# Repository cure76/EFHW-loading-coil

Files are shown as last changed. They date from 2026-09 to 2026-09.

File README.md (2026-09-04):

# Удлиняющая катушка EFHW 100 мкГн

Параметрические модели OpenSCAD: каркас однослойной катушки и седло клеммы полотна под М4.

## Файлы

| Файл | Что печатать |
| --- | --- |
| `EFHW_Loading_Coil_100_mkgn_1mm.scad` | Каркас (1 шт.) |
| `EFHW_terminal_saddle_M4.scad` | Седло клеммы (2 шт.) |

Превью обмотки и термоусадки в каркасе (`show_winding`, `show_shrink`) только в F5, в STL не попадают.

После F5/F6 смотри консоль OpenSCAD (`echo`): витки, длины, Ø буртика, Ø термоусадки.

## Каркас (дефолты)

- Индуктивность по Уилеру 1928, однослойно, виток к витку
- Диаметр намотки (наружный Ø трубы) **55 мм**
- Провод **ПЭТВ-2 1 мм** (медь 1.0 мм, с эмалью ≈ 1.093 мм)
- Стенка 2 мм, канал сквозной (охлаждение)
- Внутри, со стороны отверстий: плоская полка **1 мм** на всю длину, по хорде до стенок канала (шайбы под М4, силовой элемент). Отверстия М4 и отводы сквозные через полку, сверлить не нужно.
- Буртики на 0.5 мм выше провода
- Отверстия: отвод обмотки **1.5 мм** вплотную к буртикам (зазор 0.3 мм), болты **М4** 4.4 мм, с одной стороны (−Y)
- `spare_turns = 8` — в окне намотки место под 8 лишних витков (до 59 вплотную)

Если сменил провод или Ø, подставь в седло `flange_od` и `shrink_wall` из echo каркаса.

## Намотка и индуктивность

Мотать **виток к витку** ПЭТВ-2 1 мм между буртиками. Начинать и кончать через отверстия 1.5 мм.

| Витки | L (Уилер), мкГн | Провод (витки) | С отводами 10 см × 2 |
| --- | --- | --- | --- |
| 51 | ≈ 99.5 | ≈ 8.99 м | ≈ 9.19 м |
| 52 | ≈ 102 | ≈ 9.16 м | ≈ 9.36 м |
| 58 | ≈ 118 | ≈ 10.22 м | ≈ 10.42 м |
| 59 | ≈ 120 | ≈ 10.40 м | ≈ 10.60 м |

Среднее Ø витка ≈ 56.1 мм (труба 55 + эмаль), ≈ 17.6 см на виток. Окно каркаса вмещает **59** витков вплотную.

Резать с запасом под окно: **10.6–11 м** ПЭТВ-2 1 мм. После намотки с каждой стороны должно остаться по ~10 см на отвод.

Практический ориентир Уилера: **примерно 100–102 мкГн** на 51–52 витках. Один виток ≈ **+2.6 мкГн**. Если прибор показывает меньше — домотай (место есть до 59).

1. Намотай **52** витка виток к витку.
2. Измерь L-метром (лучше на каркасе, как будет в антенне).
3. Если меньше 100 — добавляй витки до 100–102 (окно до 59).
4. Если больше 100–102 — сними лишнее.
5. Не растягивай витки: шаг заложен виток к витку.

Цифры — расчёт Уилера для воздушного каркаса. Печать и лак чуть сдвинут L; ориентир — прибор, не echo.

## Сборка

1. Намотка, отводы через 1.5 мм на болты М4 (гайка внутри канала).
2. Лак, сушка.
3. Термоусадка **на всю катушку**, включая буртики; стержни М4 снаружи. Мин. внутр. Ø трубки до усадки — в echo (дефолт ≥ ~60 мм).
4. Два седла **поверх усадки** (не на голый пластик). Одна жила **П-274М** (Ø ≤ 2.3 мм) в щель 3 мм под шляпку, петля на болт. Снутри на плоскую полку — шайба М4 и гайка.

Седло по умолчанию под Ø буртика 58.186 мм и стенку усадки 0.6 мм.

## Мощность (оценка, не паспорт)

Каркас PETG + усадка на всё. Узкое место — нагрев, не медь.

| Режим | Ориентир |
| --- | --- |
| SSB | до 100 Вт PEP |
| CW | 50–70 Вт |
| FT8 | 20–40 Вт |

После FT8 каркас должен быть тёплым, не обжигающим.

## Печать

Предпочтительно **PETG** (улица, УФ). PLA для постоянной установки хуже.

Тесты расчёта Уилера:

```bash
cd tests && python3 -m unittest test_coil_math -v
```

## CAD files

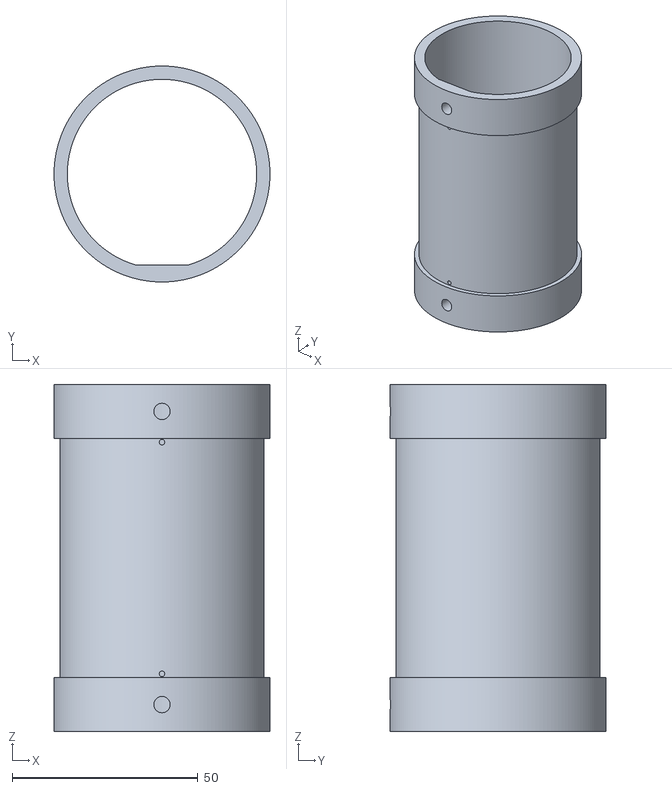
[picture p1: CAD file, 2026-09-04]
EFHW_Loading_Coil_100_mkgn_1mm.stl
58.2 x 58.2 x 93.5

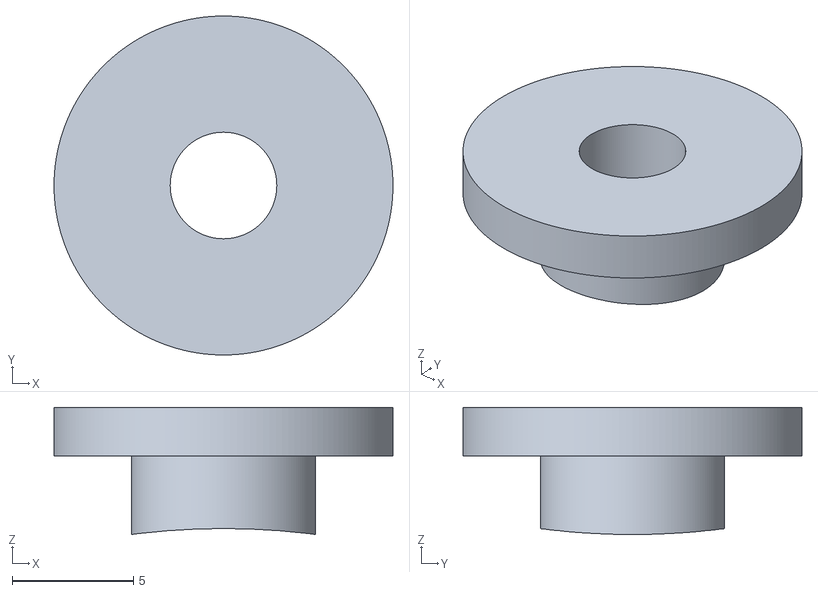
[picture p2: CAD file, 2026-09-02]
EFHW_terminal_saddle_M4.stl
14.0 x 14.0 x 5.25

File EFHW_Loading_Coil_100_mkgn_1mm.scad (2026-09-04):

$fn = $preview ? 64 : 160;

/* [Coil] */
L_uH = 100;
winding_d = 55;
wire_cu_d = 1.0;
wire_od = 0; // 0 = авто ПЭТВ-2

/* [Former] */
wall = 2;
flange_len = 14.5;
flange_over_wire = 0.5;
m4_d = 4.4;
lead_d = 1.5; // отверстие под отвод ПЭТВ-2
lead_flange_gap = 0.3; // зазор от края отверстия до буртика, мм
spare_turns = 8; // запас окна намотки (витков)
rib_t = 1; // полка внутрь канала, мм (хорда до стенок цилиндра)

/* [Preview] */
show_winding = false;
show_shrink = false;
shrink_wall = 0.6;

function in_from_mm(mm) = mm / 25.4;

function petv2_od(cu_d) = cu_d + 0.093;

function wire_od_eff(cu_d, od) = od <= 0 ? petv2_od(cu_d) : od;

function wheeler_n(L, r_mm, pitch_mm) =
    let (
        r = in_from_mm(r_mm),
        p = in_from_mm(pitch_mm),
        disc = pow(10 * L * p, 2) + 36 * L * pow(r, 3)
    )
    (10 * L * p + sqrt(disc)) / (2 * r * r);

function wheeler_L(N, r_mm, pitch_mm) =
    let (
        r = in_from_mm(r_mm),
        ell = in_from_mm(N * pitch_mm)
    )
    r * r * N * N / (9 * r + 10 * ell);

od = wire_od_eff(wire_cu_d, wire_od);
inner_d = winding_d - 2 * wall;
pitch = od;
r_mm = (winding_d + od) / 2;
N_exact = wheeler_n(L_uH, r_mm, pitch);
N_finite = N_exact == N_exact && N_exact > 0 && N_exact < 1e6;
N = N_finite ? max(1, round(N_exact)) : 0;
winding_len = (N + spare_turns) * pitch;
length = winding_len + 2 * flange_len;
flange_od = winding_d + 2 * (od + flange_over_wire);
L_actual = N_finite ? wheeler_L(N, r_mm, pitch) : 0;
use_mid_leads = (winding_len - 2 * lead_d - 2 * lead_flange_gap) < lead_d;
rib_w = (rib_t > 0 && rib_t < inner_d / 2)
    ? 2 * sqrt(pow(inner_d / 2, 2) - pow(inner_d / 2 - rib_t, 2))
    : 0;
rib_ok = rib_t > 0 && rib_t < inner_d / 2 && rib_w > m4_d;
geometry_ok = inner_d > 0 && N_finite && winding_len > 0 && spare_turns >= 0 && rib_ok;

function lead_z(sign) =
    use_mid_leads
        ? sign * winding_len / 4
        : sign * (winding_len / 2 - lead_d / 2 - lead_flange_gap);

module radial_cut(d, z) {
    translate([0, 0, z])
        rotate([90, 0, 0])
            cylinder(h = flange_od / 2 + 5, d = d, center = false);
}

module inner_rib() {
    intersection() {
        cylinder(h = length, d = inner_d, center = true);
        translate([0, -inner_d / 2 + rib_t / 2, 0])
            cube([inner_d + 1, rib_t, length], center = true);
    }
}

module former() {
    difference() {
        union() {
            difference() {
                cylinder(h = length, d = winding_d, center = true);
                cylinder(h = length + 2, d = inner_d, center = true);
            }
            for (z = [-(length / 2 - flange_len / 2), length / 2 - flange_len / 2])
                translate([0, 0, z])
                    difference() {
                        cylinder(h = flange_len, d = flange_od, center = true);
                        cylinder(h = flange_len + 1, d = winding_d, center = true);
                    }
            inner_rib();
        }
        for (sign = [-1, 1]) {
            radial_cut(m4_d, sign * (length / 2 - flange_len / 2));
            radial_cut(lead_d, lead_z(sign));
        }
    }
}

module preview_winding() {
    difference() {
        cylinder(h = winding_len, d = winding_d + 2 * od, center = true);
        cylinder(h = winding_len + 1, d = winding_d, center = true);
    }
}

module preview_shrink() {
    difference() {
        cylinder(h = length, d = flange_od + 2 * shrink_wall, center = true);
        cylinder(h = length + 1, d = flange_od, center = true);
    }
}

module echo_recipe() {
    if (!geometry_ok) {
        echo("ОШИБКА: неверные параметры (стенка, L или провод). Геометрию не строим.");
        echo("inner_d=", inner_d, " N_exact=", N_exact, " winding_len=", winding_len);
    } else {
        echo("Витки N=", N, " (точно ", N_exact, "), резерв=", spare_turns);
        echo("Окно намотки мм=", winding_len, " (N + резерв)");
        echo("L факт мкГн=", L_actual, " (для N витков; лишний виток снять при подстройке)");
        echo("Длина каркаса мм=", length);
        echo("Ø буртика мм=", flange_od);
        echo("Ø канала мм=", inner_d);
        echo("Ø отвода мм=", lead_d, " зазор до буртика мм=", lead_flange_gap, " Ø М4 мм=", m4_d);
        echo("Полка внутри: толщина мм=", rib_t, " ширина хорды мм=", rib_w, " (сливается со стенкой, отверстия сквозные)");
        echo("Мин. внутр. Ø термоусадки до усадки мм=", flange_od + 2);
        echo("Сборка: лак → отводы на М4 (гайка в канале) → усадка на всю катушку, болты снаружи");
        if (lead_d >= flange_od / 2)
            echo("ПРЕДУПРЕЖДЕНИЕ: отверстие отвода очень большое относительно каркаса");
    }
}

echo_recipe();

if (geometry_ok) {
    former();
    if ($preview && show_winding)
        color("gold", 0.7) preview_winding();
    if ($preview && show_shrink)
        color("silver", 0.35) preview_shrink();
}

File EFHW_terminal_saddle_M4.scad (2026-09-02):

$fn = $preview ? 64 : 160;

/* [Shayba] */
m4_d = 4.4;
flange_od = 58.186; // голый буртик, echo каркаса
shrink_wall = 0.6;
gap = 3.0; // над усадкой, жила П-274М ≤ 2.3 мм
hat_d = 14;
hat_h = 2.0;
stem_od = 7.6;

saddle_od = flange_od + 2 * shrink_wall;
R = saddle_od / 2;

geometry_ok =
    gap >= 2.3
    && m4_d < stem_od
    && stem_od < hat_d
    && flange_od > 0
    && hat_h > 0
    && shrink_wall >= 0;

module echo_recipe() {
    if (!geometry_ok) {
        echo("ОШИБКА: неверные параметры шайбы. Геометрию не строим.");
        echo("gap=", gap, " m4_d=", m4_d, " stem_od=", stem_od, " hat_d=", hat_d);
    } else {
        echo("Ø М4 мм=", m4_d);
        echo("Ø голого буртика мм=", flange_od);
        echo("Стенка усадки мм=", shrink_wall);
        echo("Ø седла (усадка) мм=", saddle_od);
        echo("Зазор под жилу мм=", gap);
        echo("Ø шляпки мм=", hat_d, " Ø ножки мм=", stem_od);
        echo("Седло под усадку, не под голый пластик. На катушку 2 детали. Жила П-274М ≤ 2.3 мм.");
        echo("Если flange_od/shrink_wall каркаса другие — подставь их сюда.");
    }
}

module shayba() {
    difference() {
        union() {
            translate([0, 0, -2])
                cylinder(h = gap + 2, d = stem_od);
            translate([0, 0, gap])
                cylinder(h = hat_h, d = hat_d);
        }
        translate([0, 0, -3])
            cylinder(h = gap + hat_h + 4, d = m4_d);
        translate([0, 0, -R])
            rotate([90, 0, 0])
                cylinder(h = hat_d + 4, d = saddle_od, center = true);
    }
}

echo_recipe();

if (geometry_ok)
    shayba();

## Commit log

2026-08-30 Параметрический каркас EFHW 100 мкГн и седло клеммы М4.
    Каркас считается по Уилеру, клемма садится на термоусадку с зазором под П-274М.
    [EFHW_Loading_Coil_100_mkgn_1mm.scad, EFHW_terminal_saddle_M4.scad]
2026-08-30 Документация по намотке и запас на 52-й виток.
    Отверстие отвода 1.5 мм, окно под 51+1 виток (~100–102 мкГн). Spec/планы superpowers заменены README.
    [EFHW_Loading_Coil_100_mkgn_1mm.scad]
2026-08-30 Готовые STL каркаса и седла клеммы М4.
    [EFHW_Loading_Coil_100_mkgn_1mm.stl, EFHW_terminal_saddle_M4.stl]
2026-09-02 Внутренняя полка 12×3 мм под шайбы М4, отверстия сквозные.
    [EFHW_Loading_Coil_100_mkgn_1mm.scad, EFHW_Loading_Coil_100_mkgn_1mm.stl]
2026-09-02 Полка по хорде 1 мм и отверстия М4 4.4 мм.
    [EFHW_Loading_Coil_100_mkgn_1mm.scad, EFHW_Loading_Coil_100_mkgn_1mm.stl, EFHW_terminal_saddle_M4.scad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]
2026-09-03 Длина провода на 51–52 витка и отводы по 10 см.
2026-09-04 Отверстия отводов у буртиков с зазором 0.3 мм.
    [EFHW_Loading_Coil_100_mkgn_1mm.scad]
2026-09-04 Запас окна намотки 8 витков (до 59 вплотную).
    [EFHW_Loading_Coil_100_mkgn_1mm.scad]
2026-09-04 STL каркаса: окно 59 витков и отводы у буртиков.
    [EFHW_Loading_Coil_100_mkgn_1mm.stl]
